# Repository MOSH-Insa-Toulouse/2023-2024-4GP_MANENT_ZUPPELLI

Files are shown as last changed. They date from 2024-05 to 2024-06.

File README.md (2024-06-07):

# 2023-2024-4GP_MANENT_ZUPPELLI
--- 
## Sommaire
   - [I) Contexte et objectifs du projet](#I-Contexteetobjectifsduprojet)
   - [II) Capteur à jauge de contrainte à base de crayon graphite](#II-Capteuràjaugedecontrainteàbasedecrayongraphite)
   - [III) Partie Analogique](#III-PartieAnalogique)
   - [IV) Code Arduino](#IV-CodeArduino)
   - [V) KiCad](#V-KiCad)
   - [VI) Banc de tests](#VI-Bancdetests)
   - [VII) Application mobile](#VII-Applicationmobile)
   - [VIII) Datasheet](#VIII-Datasheet)
     
---
  
## I) Contexte et objectifs du projet

L'objectif de ce projet est de réaliser un capteur low-tech à base de graphite. Les recherches ont démontré les nombreux avantages du carbone graphite. L’électronique à base de papier gagne en popularité parmi les ingénieurs grâce à sa facilité d’approvisionnement, sa simplicité de fabrication et son faible coût.<br>
Nous avons dû réaliser tous les processus de fabrication d'un shield PCB. Nous l'avons ensuite connecté à une plaque Arduino UNO.<br>
Notre shield contient 6 composants différents : une jauge de contrainte, un flex sensor, un écran oled, un encodeur rotatoire, un potentiomètre digital et un module Bluetooth.<br>
Par ailleurs, la carte Arduino fonctionne avec un code.<br>
Nous avons ensuite réalisé une application mobile connectée au module bluetooth.<br>
Nous avons évalué le capteur sur un banc de test.<br>
Puis nous avons fini par réaliser la datasheet du capteur de contrainte.<br>

## II)Capteur à jauge de contrainte à base de crayon graphite

Ce capteur low-tech utilise la théorie de la percolation au sein d’un système granulaire constitué de nanoparticules de graphite.<br>
Nous déposons une fine couche de graphite sur la feuille de papier ce qui présente un réseau percolé caractéristique. Dans ce réseau, le transport des électrons entre les nanoparticules est basé sur le mécanisme de l’effet tunnel.<br>
Lors de l'application d'une tension, le réseau percolé se trouve directement étendu. Cette déformation entraîne une augmentation de la distance effective entre les particules de graphite au sein du réseau. Une partie des chemins de percolation sont par conséquent rompus. Ainsi, la conduction du matériau diminue, donc la résistance de la couche de graphite augmente.<br>
Inversement, lors de l’application de déformations en compression, le réseau percolé se trouve directement comprimé. Cette déformation entraîne une diminution de la distance effective entre les particules.<br> Ainsi, de nouveaux chemins de percolation sont créés, la conduction du matériau augmente, soit la résistance de la couche de graphite diminue.

Une jauge de contrainte est un circuit résistif dont la résistance varie en fonction de sa déformation. Donc en mesurant les variations de résistance de la jauge, nous en avons déduit la contrainte et la déformation appliquées.<br>
Notre jauge de contrainte est alimentée par une tension régulée de 5V d'une carte Arduino UNO.
<br>
Ci-dessous, les 4 différentes jauges de contrainte que nous avons utilisé dans ce projet.

<p align="center">
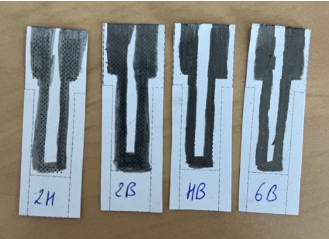
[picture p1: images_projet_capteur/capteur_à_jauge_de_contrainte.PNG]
Figure 1 - Capteur à jauge de contrainte à base de crayon graphite

<br>
<i>Capteur à jauge de contrainte à base de crayon graphite</i>
</p>

## III) Partie Analogique

Ce capteur graphite possède une résistance variable de l'ordre du GΩ. Le courant généré lorsque l'on applique une tension de 5V aux bornes du capteur est très faible.<br>
Pour obtenir un signal exploitable nous avons dû l'amplifier. Pour ce faire, nous avons utilisé un montage transimpédance constitué d'un amplificateur opérationnel.<br>
Pour cela nous avons dans un premier temps effectué une simulation électronique du capteur et de ce montage transimpédance sous LTSpice. Voici ci-dessous le montage réalisé sous LTSpice. Pour notre montage nous avons choisi l'AOP LTC1050 prenant en entrée un courant faible (de l'ordre d'une dizaine de picoampère).

<p align="center">
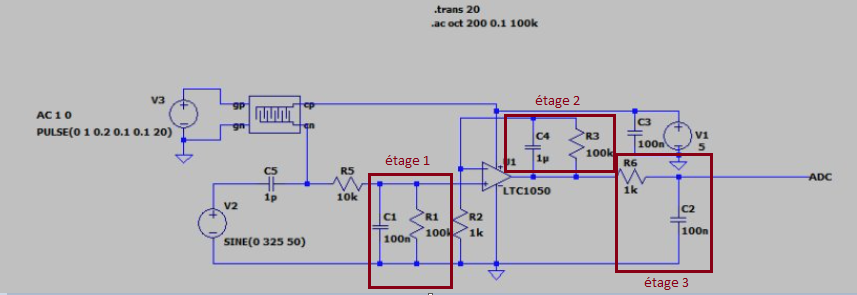
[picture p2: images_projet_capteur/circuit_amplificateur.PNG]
Circuit amplificateur réalisé dans LTSpice

<br>
<i>Circuit amplificateur réalisé dans LTSpice</i>
</p>
<br>
Ce circuit amplificateur contient également 3 filtres passe bas passifs, dont nous avons pu tester le bon fonctionnement alternativement.<br>
<br>
- Le premier étage a une fréquence de coupure de 16 Hz, il permet de filtrer les bruits du courant en entrée. Nous avons testé ce premier étage pour vérifier que la fréquence de coupure soit la bonne.
<br>
</p>
<p align="center">
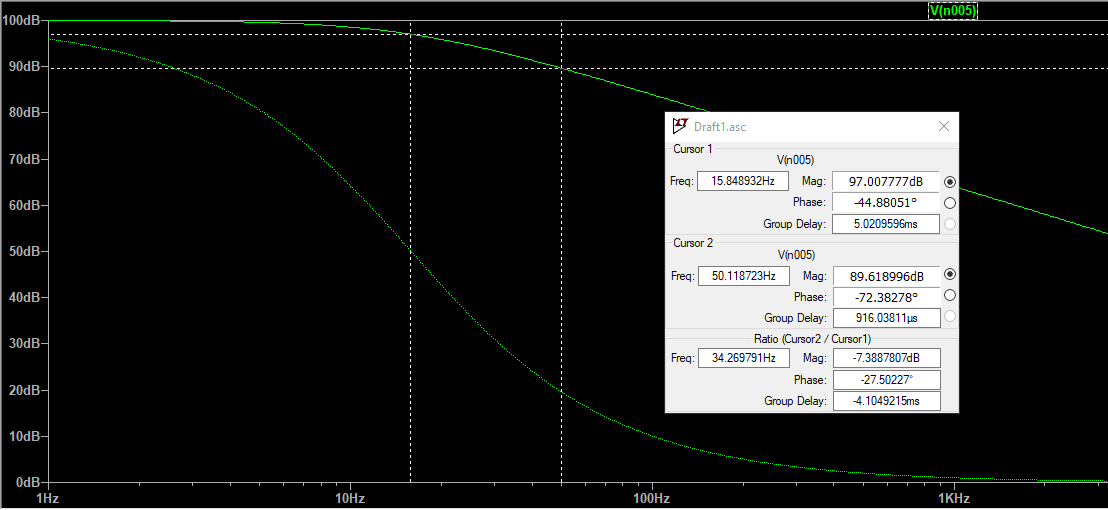
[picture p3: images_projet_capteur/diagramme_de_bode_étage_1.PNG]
Simulation de l'étage 1 dans LTSpice

<br>
<i>Simulation de l'étage 1 dans LTSpice</i>
</p>
En effet la fréquence de coupure est la bonne.
<br>
- Le second étage a une fréquence de coupure de 1,6 Hz. Il permet de filtrer la composante de bruit du réseau électrique: le bruit à 50 Hz.
<br>
</p>
<p align="center">
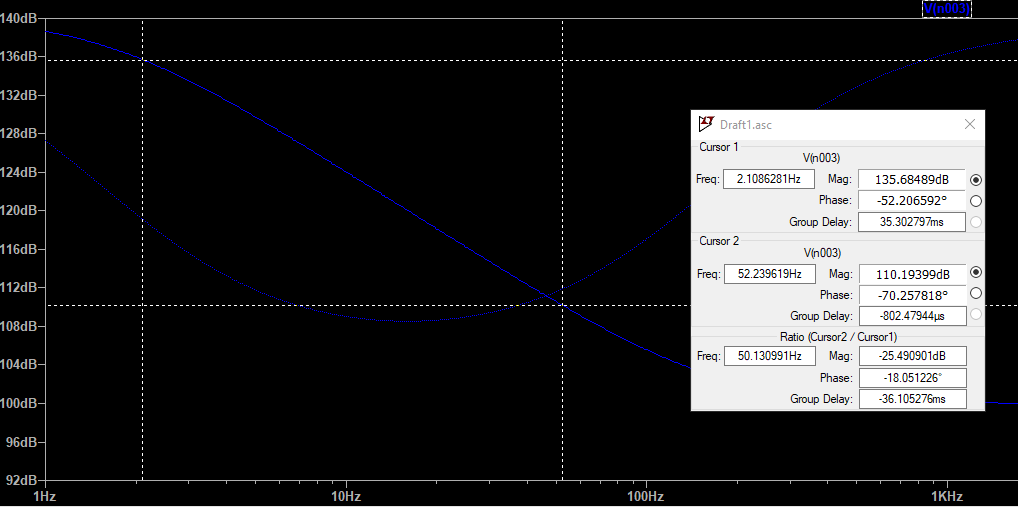
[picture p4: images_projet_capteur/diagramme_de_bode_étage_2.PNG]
Simulation de l'étage 2 dans LTSpice

<br>
<i>Simulation de l'étage 2 dans LTSpice</i>
</p>
En effet la fréquence de coupure est la bonne.
<br>
- Le dernier étage a une fréquence de coupure à 1,6 kHz qui permet d'atténuer le bruit provenant lors du traitement électronique.
<br>
</p>
<p align="center">
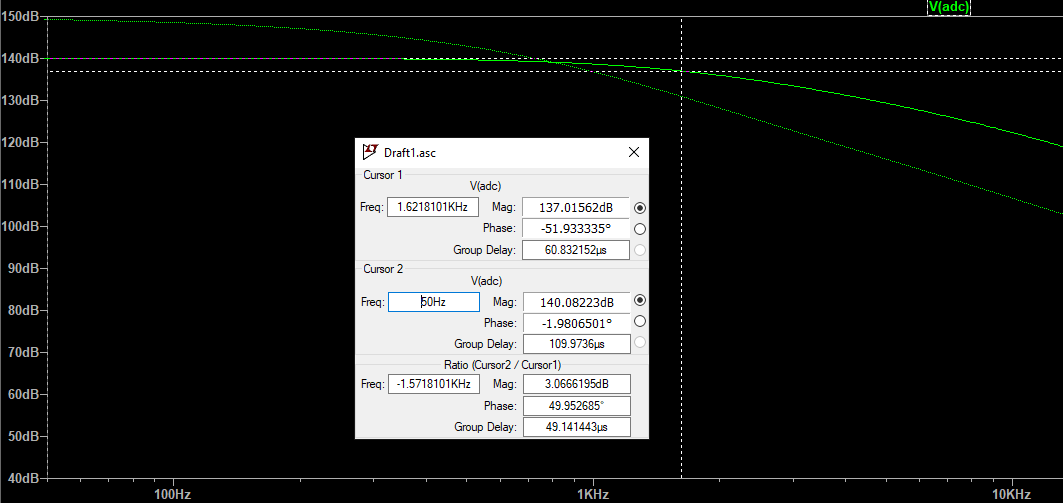
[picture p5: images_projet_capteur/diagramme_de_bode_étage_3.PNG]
Simulation de l'étage 3 dans LTSpice

<br>
<i>Simulation de l'étage 3 dans LTSpice</i>
</p>
En effet la fréquence de coupure est la bonne.
<br> 
Conclusion : grâce à la simulation sur LTSpice, nous remarquons que notre signal de sortie atteindra les 1V, ce qui lui permet d'être récupéré et exploité par la carte arduino UNO.

## IV) Code Arduino

Le code Arduino permet la réception des mesures faites par les deux capteurs (Graphites et Flex Sensor) et d'afficher ces valeurs sur l'OLED. 
Notre programme principal est composé de sous programmes associés à ces éléments:
<br>
<p align="center">
Figure 2 - Capteur à jauge de contrainte à base de crayon graphite
<br>
<i>Capteur graphite</i>
<br>   
<p align="center">
Figure 3 - Flex Sensor
<br>
<i>Flex Sensor</i>
<br>   
<p align="center">
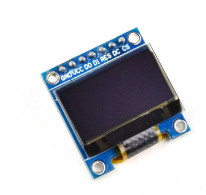
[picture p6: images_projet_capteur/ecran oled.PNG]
Figure 4 - Ecran OLED

<br>
<i>Ecran OLED</i>
<br>   
<p align="center">
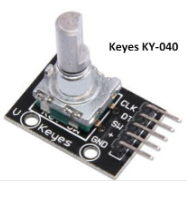
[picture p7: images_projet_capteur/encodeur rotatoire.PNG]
Figure 5 - Encodeur rotatoire

<br>
<i>Encodeur rotatoire</i>
<br>   
<p align="center">
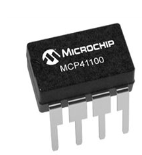
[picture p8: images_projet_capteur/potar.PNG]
Figure 6 - Potentiomètre digital

<br>
<i>Potentiomètre digital</i>
<br>   
<p align="center">
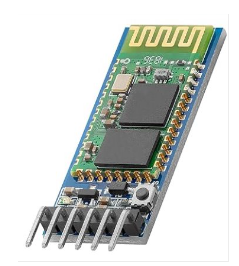
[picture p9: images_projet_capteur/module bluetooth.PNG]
Figure 7 - Module Bluetooth

<br>
<i>Module Bluetooth</i>

## V) KiCad
Avant d'imprimer le PCB et de souder nos différents composants, nous avons dû dessiner les schémas électroniques, réaliser les composants électroniques et créer le PCB sur KICAD. Cette étape est importante car elle permet de prévisualiser le PCB, vérifier que tous les composants tiennent sur le PCB. Elle permet également de créer les différents routages de pistes.

<p align="center">
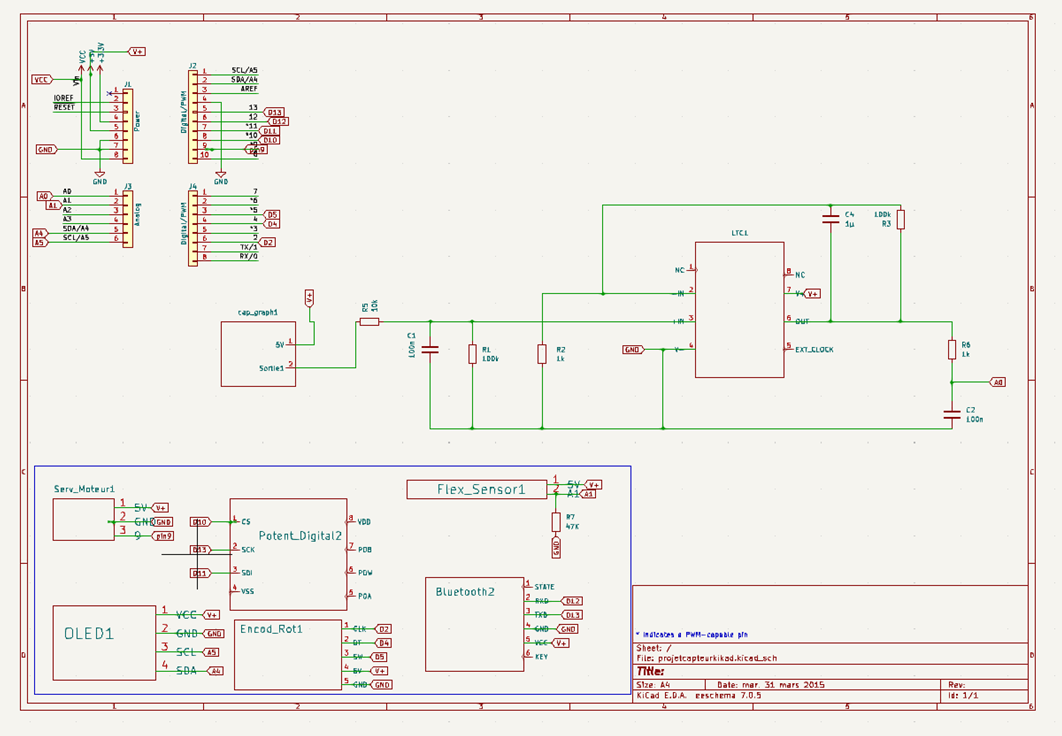
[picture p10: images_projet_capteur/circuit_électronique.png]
Schémas électroniques

<br>
<i>Schémas électroniques</i>
</p>

<p align="center">
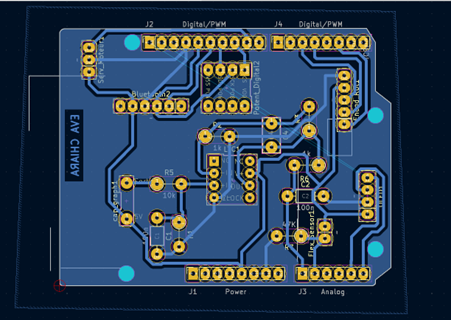
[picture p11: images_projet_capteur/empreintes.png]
Création du PCB et des différentes empreintes sur KiCad

<br>
<i>Création du PCB et des différentes empreintes sur KiCad</i>
</p>

<p align="center">
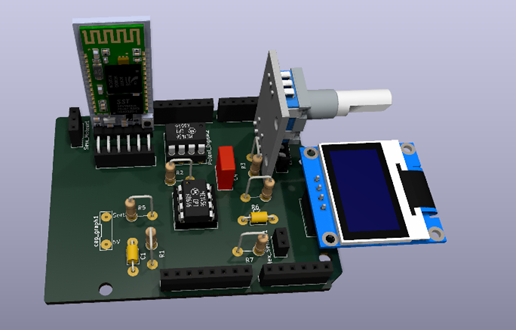
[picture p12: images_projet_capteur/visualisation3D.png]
Visualisation 3D du PCB

<br>
<i>Visualisation 3D du PCB</i>
</p>
<br>
Une fois que nous avons été satisfaites de la disposition de nos différents composants électroniques, et du routage de pistes, nous avons pu imprimer le PCB, le percer et y souder les différents composants.
<br>
<br>
<p align="center">
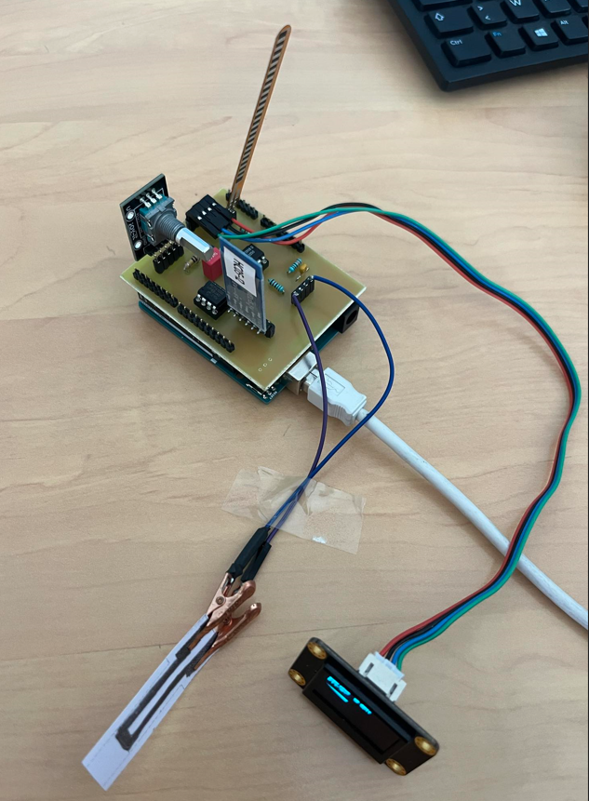
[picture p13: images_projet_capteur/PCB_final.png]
PCB terminé

<br>
<i>PCB terminé</i>
</p>

## VI) Banc de tests

Nous avons relevé la variation de résistance de notre capteur en fonction de son angle de déformation. Pour cela, nous avons fabriqué un banc de test avec des disques en papiers de rayons de courbure différents:
<br> 
<p align="center">
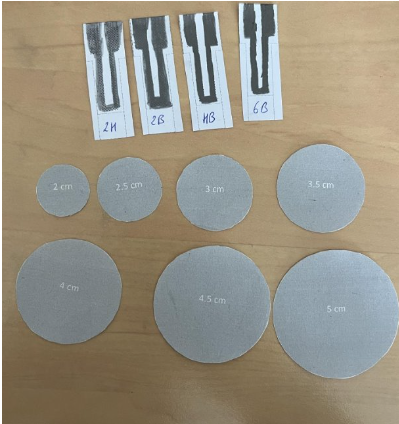
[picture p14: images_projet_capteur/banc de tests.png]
Figure 8 - Banc de tests

<br> 
<i>Banc de tests</i>
<br>

Nous avons réalisé les mesures pour une déformation du capteur en traction et en compression. Nous avons testé plusieurs crayons graphites qui ont des duretés différentes: 2H, 2B, HB, 6B. Les détails des calculs se trouvent sur le document nommé "bancdetest.xlsx"
<br>

Voici les résultats obtenus: 

<br>
<p align="center">
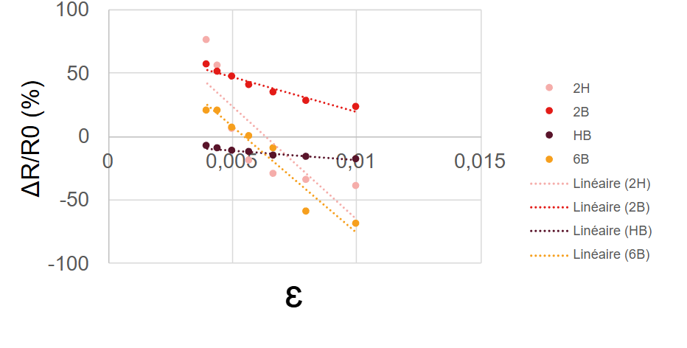
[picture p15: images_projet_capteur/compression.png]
graphique représentant la variation de résistance relative en fonction de la compression appliquée

<br>
<i>graphique représentant la variation de résistance relative en fonction de la compression appliquée</i>
</p>
<br>

<br>
<p align="center">
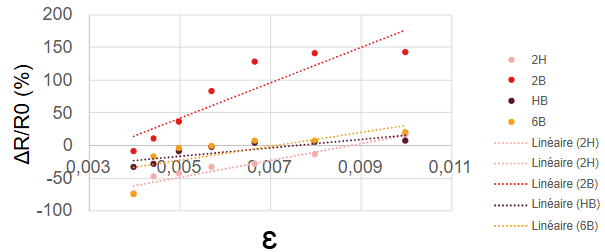
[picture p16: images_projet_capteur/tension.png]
graphique représentant la variation de résistance relative en fonction de la tension appliquée

<br>
<i>graphique représentant la variation de résistance relative en fonction de la tension appliquée</i>
</p>
<br>

Nous pouvons remarquer que les résistances des mines de crayon les plus tendres sont plus faibles que celles des mines les plus dures. En effet, les mines les plus tendres contiennent plus de particules de graphites, donc les traces de crayons paraissent plus foncées. Au contraire, les mines les plus dures contiennent moins de particules de graphites et plus de liants argileux donc elles paraissent les traces de crayons paraissent plus claires. Sous compression, les particules de graphites se rapprochent donc le courant circule plus facilement: la résistance diminue. A l'inverse, sous traction, les particules de graphites s'écartent ce qui facilite la déconnexion des voies de conduction donc le courant circule moins facilement: la résistance augmente.

## VII) Application mobile

Nous avons réalisé une application mobile sur le site MIT App Inventor. <br>
Une fois que le module bluetooth est connecté au téléphone, nous pouvons acquérir les données des capteurs en temps réel et les tracer sur le graphe. 

<br> 
<p align="center">
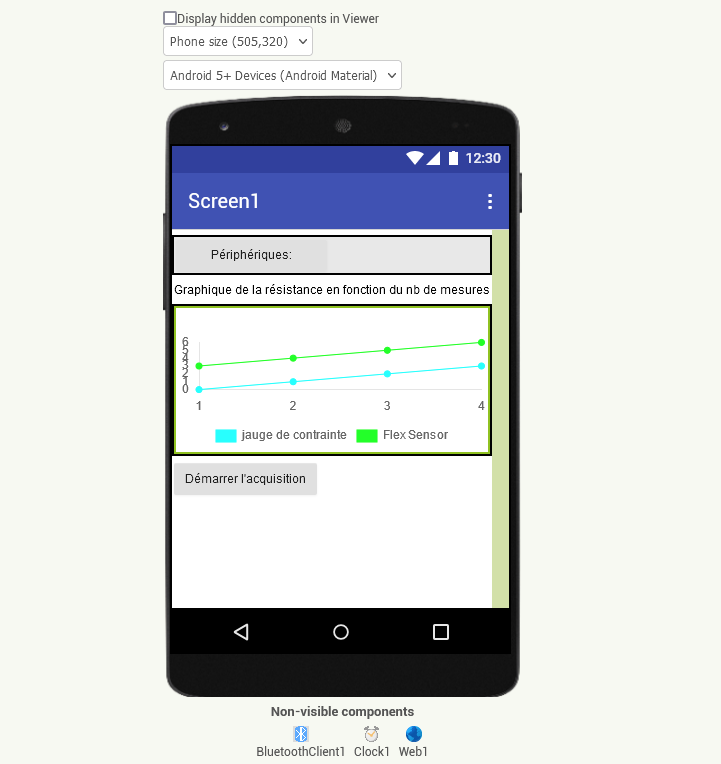
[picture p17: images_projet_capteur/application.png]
Face avant de l'application

<br> 
<i>Face avant de l'application</i>
<br>

## VIII) Datasheet
<br> 
Nous avons déposé le PDF de la datasheet.

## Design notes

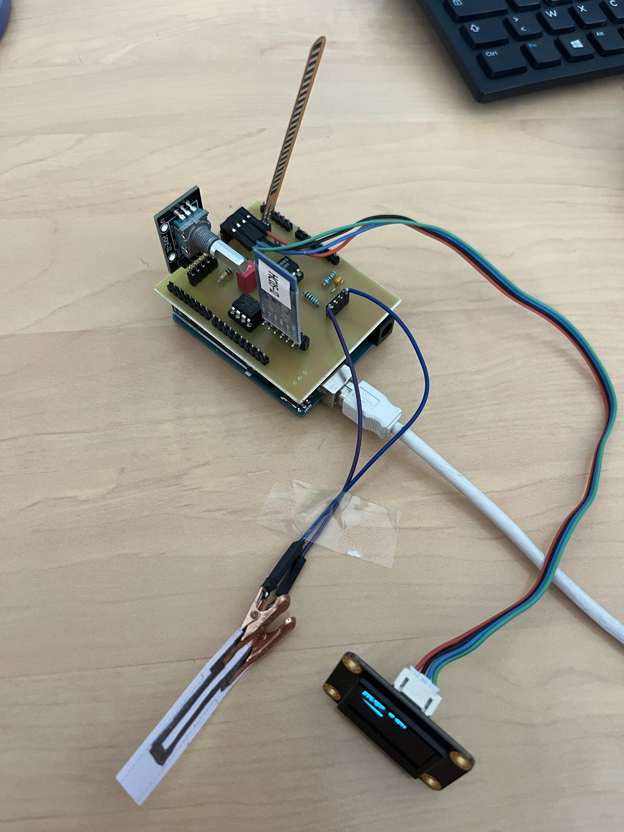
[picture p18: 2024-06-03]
images_projet_capteur/pcb terminé.jpg

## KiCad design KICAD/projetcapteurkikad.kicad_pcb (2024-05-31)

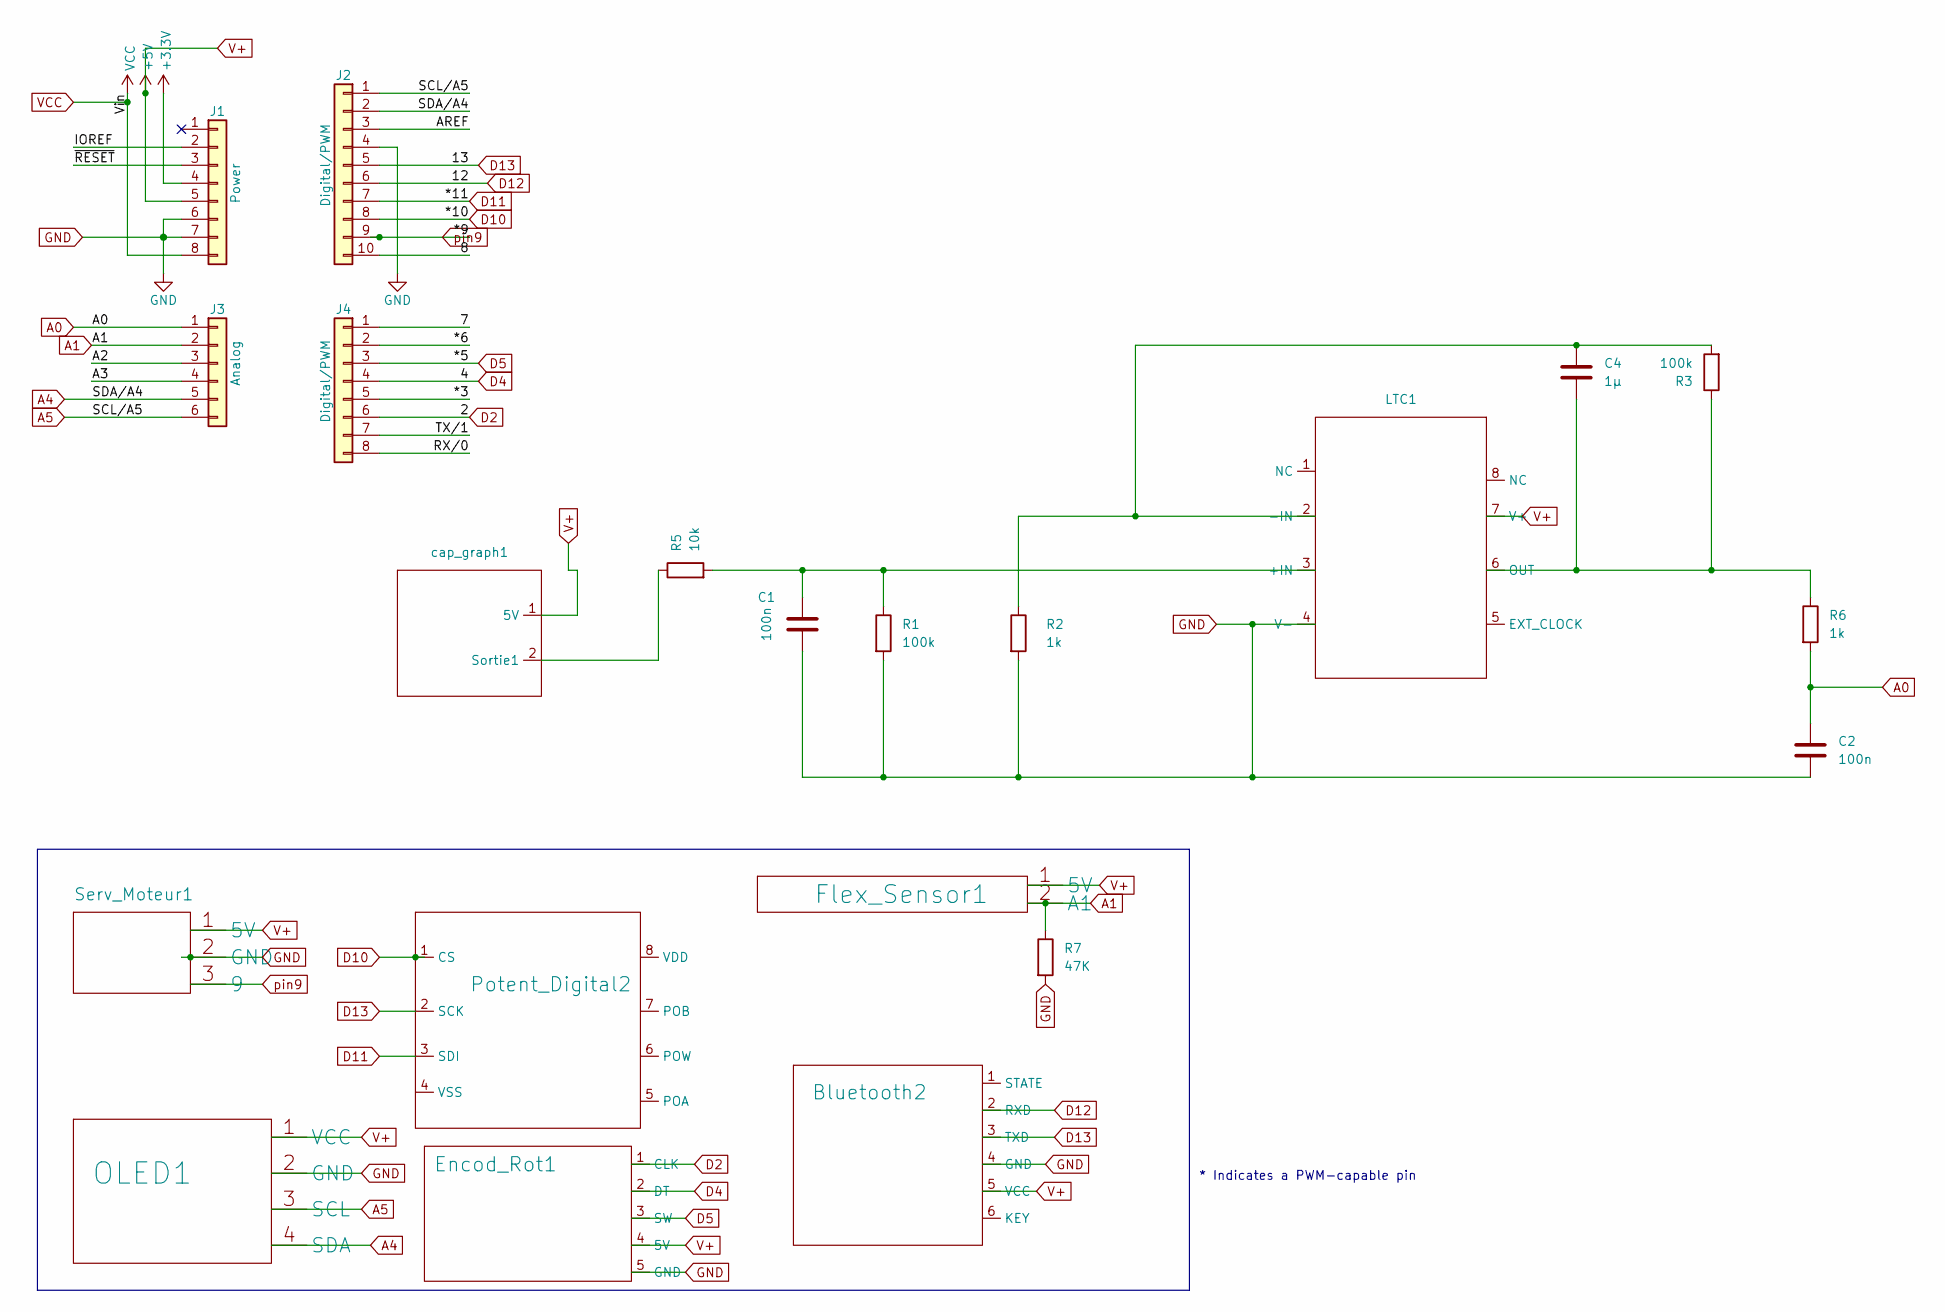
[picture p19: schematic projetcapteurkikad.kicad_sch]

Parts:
Bluetooth2: Bluetooth2
C1, C2: 100n; C_Axial_L3.8mm_D2.6mm_P7.50mm_Horizontal
C4: 1µ; C_Rect_L7.2mm_W3.5mm_P5.00mm_FKS2_FKP2_MKS2_MKP2
Encod_Rot1: Encod_Rot2
Flex_Sensor1: SIP-2
J1: Power; PinSocket_1x08_P2.54mm_Vertical
J2: Digital/PWM; PinSocket_1x10_P2.54mm_Vertical
J3: Analog; PinSocket_1x06_P2.54mm_Vertical
J4: Digital/PWM; PinSocket_1x08_P2.54mm_Vertical
LTC1: LTC1050
OLED1: OLED_new
Potent_Digital2: Potentiometre_Digital3
R1, R3: 100k; R_Axial_DIN0207_L6.3mm_D2.5mm_P5.08mm_Vertical
R2, R6: 1k; R_Axial_DIN0207_L6.3mm_D2.5mm_P5.08mm_Vertical
R5: 10k; R_Axial_DIN0207_L6.3mm_D2.5mm_P5.08mm_Vertical
R7: 47K; R_Axial_DIN0207_L6.3mm_D2.5mm_P5.08mm_Vertical
Serv_Moteur1: Servomoteur
cap_graph1: capp_graph

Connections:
+3V3: J1.4
/7: J4.1
/8: J2.10
/*3: J4.5
/*6: J4.2
/A2: J3.3
/A3: J3.4
/AREF: J2.3
/IOREF: J1.2
/RX/0: J4.8
/TX/1: J4.7
/~RESET: J1.3
A0: C2.1, J3.1, R6.2
A1: Flex_Sensor1.2 (A1), J3.2, R7.1
A4: J2.2, J3.5, OLED1.4 (SDA)
A5: J2.1, J3.6, OLED1.3 (SCL)
D2: Encod_Rot1.1 (CLK), J4.6
D4: Encod_Rot1.2 (DT), J4.4
D5: Encod_Rot1.3 (SW), J4.3
D10: J2.8, Potent_Digital2.1 (CS)
D11: J2.7, Potent_Digital2.3 (SDI)
D12: Bluetooth2.2 (RXD), J2.6
D13: Bluetooth2.3 (TXD), J2.5, Potent_Digital2.2 (SCK)
GND: Bluetooth2.4 (GND), C1.2, C2.2, Encod_Rot1.5 (GND), J1.6, J1.7, J2.4, LTC1.4 (V-), OLED1.2 (GND), R1.2, R2.2, R7.2, Serv_Moteur1.2 (GND)
unnamed: C1.1, LTC1.3 (+IN), R1.1, R5.2
unnamed: C4.1, LTC1.2 (-IN), R2.1, R3.2
unnamed: C4.2, LTC1.6 (OUT), R3.1, R6.1
unnamed: R5.1, cap_graph1.2 (Sortie1)
V+: Bluetooth2.5 (VCC), Encod_Rot1.4 (5V), Flex_Sensor1.1 (5V), J1.5, LTC1.7 (V+), OLED1.1 (VCC), Serv_Moteur1.1 (5V), cap_graph1.1 (5V)
VCC: J1.8
pin9: J2.9, Serv_Moteur1.3 (9)

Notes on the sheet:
* Indicates a PWM-capable pin

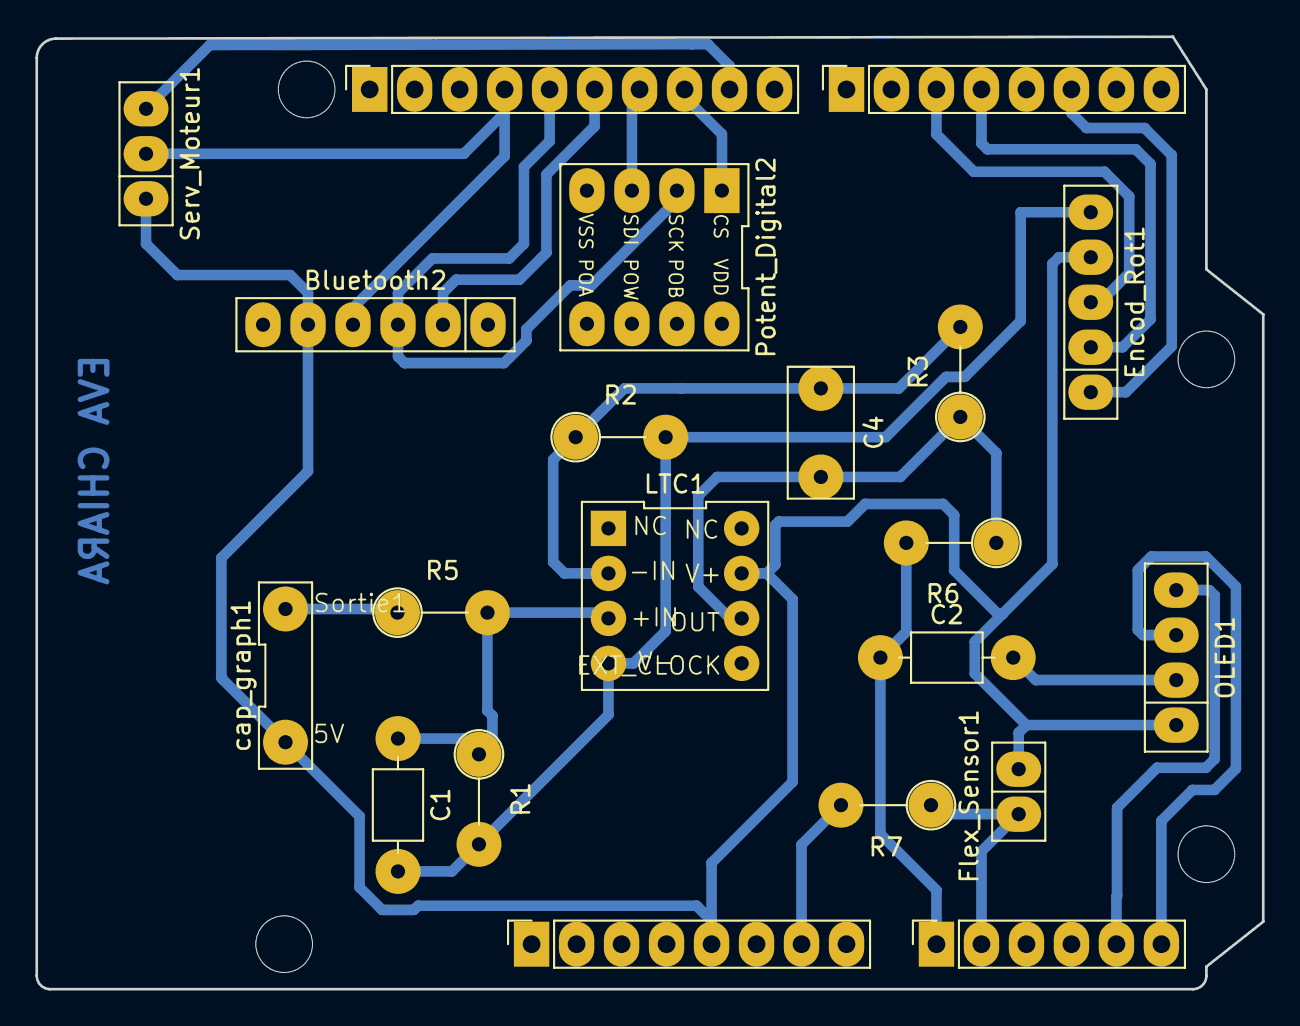
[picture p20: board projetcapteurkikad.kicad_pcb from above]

Board: 2 copper layers, 69.2 x 53.8 mm, 25 parts (0 on the bottom side), 18 nets.

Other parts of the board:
MH1, MH2, MH3, MH4: MountingHole_3.2mm

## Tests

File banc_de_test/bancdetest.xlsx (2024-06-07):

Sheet: Tension
diamètre (mm) | epaisseur (mm) |  | R0 (Ω) |  | 2H | 2B | HB | 6B
20 | 0.2 | 2H | 20 | déformation | R (Ω) | R (Ω) | R (Ω) | R (Ω)
25 | 0.2 | 2B | 423 | 0.01 | 23 | 1019 | 1019 | 59
30 | 0.2 | HB | 960 | 0.008 | 17 | 1012 | 1000 | 53
35 | 0.2 | 6B | 50 | 0.006666666667 | 14 | 960 | 980 | 53
40 | 0.2 |  |  | 0.005714285714 | 13 | 770 | 918 | 49
45 | 0.2 |  |  | 0.005 | 11 | 570 | 860 | 47
50 | 0.2 |  |  | 0.004444444444 | 10 | 460 | 670 | 41
 |  |  |  | 0.004 | 5 | 380 | 630 | 12
 |  |  |  | déformation | ΔR/R0 (%) | ΔR/R0 (%) | ΔR/R0 (%) | ΔR/R0 (%)
 |  |  |  | 0.01 | 15 | 140.8983452 | 6.145833333 | 18
 |  |  |  | 0.008 | -15 | 139.2434988 | 4.166666667 | 6
 |  |  |  | 0.006666666667 | -30 | 126.9503546 | 2.083333333 | 6
 |  |  |  | 0.005714285714 | -35 | 82.03309693 | -4.375 | -2
 |  |  |  | 0.005 | -45 | 34.75177305 | -10.41666667 | -6
 |  |  |  | 0.004444444444 | -50 | 8.747044917 | -30.20833333 | -18
 |  |  |  | 0.004 | -75 | -10.16548463 | -34.375 | -76
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

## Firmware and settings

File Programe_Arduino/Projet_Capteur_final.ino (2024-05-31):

/*
  AnalogReadSerial

  Reads an analog input on pin 0, prints the result to the Serial Monitor.
  Graphical representation is available using Serial Plotter (Tools > Serial Plotter menu).
  Attach the center pin of a potentiometer to pin A0, and the outside pins to +5V and ground.

  This example code is in the public domain.

  https://www.arduino.cc/en/Tutorial/BuiltInExamples/AnalogReadSerial
*/

//oled
#include <Adafruit_SSD1306.h>
#include <SPI.h>
#include <Adafruit_GFX.h>
#include <SoftwareSerial.h>
#define nombreDePixelsEnLargeur 128         // Taille de l'écran OLED, en pixel, au niveau de sa largeur
#define nombreDePixelsEnHauteur 64          // Taille de l'écran OLED, en pixel, au niveau de sa hauteur
#define brocheResetOLED         -1          // Reset de l'OLED partagé avec l'Arduino (d'où la valeur à -1, et non un numéro de pin)
#define adresseI2CecranOLED     0x3C        // Adresse de "mon" écran OLED sur le bus i2c (généralement égal à 0x3C ou 0x3D)
#define DEBUG
#define MCP_NOP 0b00000000
#define MCP_WRITE 0b00010001
#define MCP_SHTDWN 0b00100001
//#include <SoftwareSerial.h>
#define baudrate 9600
#include <Adafruit_SSD1306.h>
#include <SPI.h>
#define SCREEN_WIDTH 128
#define SCREEN_HEIGHT 64
#define OLED_RESET -1
#define OLED_ADDRESS 0x3C
#include <SoftwareSerial.h>
#define baudrate 9600
SoftwareSerial mySerial (12, 13);
int consigne=0;

#define CLK  2  //CLK Output A Do not use other pin for clock as we are using interrupt
#define DT  4  //DT Output B
#define Switch 5 // Switch connection if available

const int ssMCPin = 10; // Define the slave select for the digital pot

#define WAIT_DELAY 5000

//Flex sensor
Adafruit_SSD1306 display(SCREEN_WIDTH, SCREEN_HEIGHT, &Wire, OLED_RESET);
const int flexPin = A1;      // Pin connected to voltage divider output
const int analogInPin = A0;
const int analogOutPin = 9;
float Rflex=0;
float Resistance=0;

// Change these constants according to your project's design
int lastStateCLK;
int lastStateDT;
int stateCLK;
int stateDT;

//bouton 
bool lastButtonState = HIGH;
bool buttonState;
bool reading;
unsigned long lastDebounceTime = 0;
unsigned long debounceDelay = 10;

int sensorValue = 0;  // value read from the pot
int outputValue = 0; 


volatile int encoder0Pos = 0;
volatile bool rotating = false;

const char* menuItems[] = {"Capteur Graph", "FlexSensor", "Gain"};
const char menuChars[] = {'A', 'B', 'C'};
int valGain = 1; // Valeur initiale pour le menu Gain

//Potentiomètre digital

#include <SPI.h>
const float VCC = 5;      // voltage at Ardunio 5V line
const float R_DIV = 47000.0;  // resistor used to create a voltage divider
const float flatResistance = 25000.0; // resistance when flat
const float bendResistance = 100000.0;  // resistance at 90 deg
const byte csPin           = 10;      // MCP42100 chip select pin
const int  maxPositions    = 256;     // wiper can move from 0 to 255 = 256 positions 
const long rAB             = 92500;   // 100k pot resistance between terminals A and B, 
                                      // mais pour ajuster au multimètre, je mets 92500
const byte rWiper          = 125;     // 125 ohms pot wiper resistance
const byte pot0            = 0x11;    // pot0 addr // B 0001 0001
const byte pot0Shutdown    = 0x21;    // pot0 shutdown // B 0010 0001



//Gestion du potentiomètre

void SPIWrite(uint8_t cmd, uint8_t data, uint8_t ssPin) // SPI write the command and data to the MCP IC connected to the ssPin
{
  SPI.beginTransaction(SPISettings(14000000, MSBFIRST, SPI_MODE0)); //https://www.arduino.cc/en/Reference/SPISettings
  
  digitalWrite(ssPin, LOW); // SS pin low to select chip
  
  SPI.transfer(cmd);        // Send command code
  SPI.transfer(data);       // Send associated value
  
  digitalWrite(ssPin, HIGH);// SS pin high to de-select chip
  SPI.endTransaction();
}



void setup() {
  // initialize serial communication at 9600 bits per second:
  Serial.begin(9600);
  pinMode(CLK, INPUT_PULLUP);
  pinMode(DT, INPUT_PULLUP);
  pinMode(Switch, INPUT_PULLUP);

  lastStateCLK = digitalRead(CLK);
  lastStateDT = digitalRead(DT);

  attachInterrupt(digitalPinToInterrupt(CLK), doEncoder, CHANGE);


  if (!display.begin(SSD1306_SWITCHCAPVCC, OLED_ADDRESS))
    while (1);

  display.clearDisplay();
  display.setTextSize(2);
  display.setTextColor(SSD1306_WHITE);
  Serial.begin(9600);
  pinMode(flexPin, INPUT);
  mySerial.begin(baudrate);
  Serial.begin(baudrate);
}
// the loop routine runs over and over again forever:
void loop() {                     // Arrêt du programme (boucle infinie) si échec d'initialisation
int ADCflex = analogRead(flexPin);
  float Vflex = ADCflex * VCC / 1023.0;
  float Rflex = R_DIV * (VCC / Vflex - 1.0);
  //Serial.print(Rflex);
  //Serial.println(Rflex);

  int sensorValue = analogRead(analogInPin);
  // map it to the range of the analog out:
  int outputValue = map(sensorValue, 0, 1023, 0, 255);
  // change the analog out value:
  analogWrite(analogOutPin, outputValue);

  // print the results to the Serial Monitor:
  Serial.print("Graphène = ");
  Serial.print(sensorValue);
  Serial.print("\t output = ");
  Serial.print(Rflex/100);
  Serial.println(outputValue);
  Serial.println("Resistance du Flex Sensor: " + String(Rflex) + " ohms");
  Serial.println();
  // wait 2 milliseconds before the next loop for the analog-to-digital
  // converter to settle after the last reading:
  delay(1000);

  if (rotating) {
    rotating = false;

  int reading = digitalRead(Switch);

  if (reading != lastButtonState) {
    lastDebounceTime = millis();
  }

  if ((millis() - lastDebounceTime) > debounceDelay) {
    if (reading != buttonState) {
      buttonState = reading;

      if (buttonState == LOW) {
        if (encoder0Pos == 2) { // Si le menu sélectionné est "Gain"
          while (digitalRead(Switch) == LOW) {} // Attend que le bouton soit relâché

          // Entrer dans le mode d'édition de la valeur de valGain
          editValGain();
          
          // Sortie de la boucle de lecture du bouton
          rotating = true; // Permet de rafraîchir l'affichage du menu après avoir édité valGain
        }
      }
    }
  }
  


  lastButtonState = reading;


    display.clearDisplay();
  display.setTextSize(1);

  for (int i = 0; i < 3; i++) {
    if (i == encoder0Pos) {
      display.setTextColor(SSD1306_BLACK, SSD1306_WHITE);
    } else {
      display.setTextColor(SSD1306_WHITE);
    }
    display.setCursor(0, i * 10);
    display.print(menuItems[i]);
    if(i == 2 && encoder0Pos == 2){
      display.print(": ");
      display.println(valGain);
    }
    if(i == 1 && encoder0Pos == 1){
      display.print(": ");
      display.println(Rflex);
  }
    if(i == 0 && encoder0Pos == 0){
      display.print(": ");
      display.println(sensorValue);   
  }
  }
  display.display();
}
}
//endodeur rotatoire

void doEncoder() {
  stateCLK = digitalRead(CLK);
  stateDT = digitalRead(DT);

  if (stateCLK != lastStateCLK) {
    if (stateDT != stateCLK) {
      encoder0Pos++;
    } else {
      encoder0Pos--;
    }

    if (encoder0Pos < 0) encoder0Pos = 2;
    else if (encoder0Pos > 2) encoder0Pos = 0;

    rotating = true;

    lastStateCLK = stateCLK;
  }

//Bluetooth
  float mesure = analogRead(Rflex);  //recup valeur capteur 
  Serial.println(mesure); //retoune la valeur 
  delay(1);
  //Serial.println(Serial.read());
//Serial.println(mySerial.available());
 while (mySerial.available()>0){
   consigne=mySerial.read();
      Serial.println(consigne,DEC);
      if (consigne==1){
        digitalWrite(13,HIGH);
      }
      if (consigne==2){
        digitalWrite(13,LOW);
      }
}
}

void editValGain() {
  display.clearDisplay();
  display.setTextSize(1);
  display.setTextColor(SSD1306_WHITE);
  display.setCursor(0, 0);
  display.print("ValGain: ");
  display.println(valGain);
  display.display();

  while (true) {
    int newPos = encoder0Pos;
    while (encoder0Pos == newPos) {
      if (digitalRead(Switch) == LOW) {
        // Valider et sortir du mode d'édition
        while (digitalRead(Switch) == LOW) {} // Attend que le bouton soit relâché
        Serial.print("Nouvelle valeur de valGain: ");
        Serial.println(valGain);
        return;
      }
    }
    if (newPos > encoder0Pos) {
      valGain++;
    } else {
      valGain--;
    }
    display.clearDisplay();
    display.setTextSize(1);
    display.setTextColor(SSD1306_WHITE);
    display.setCursor(0, 0);
    display.print("ValGain: ");
    display.println(valGain);
    display.display();
  }
}

//SoftwareSerial mySerial(rxPin,txPin);
